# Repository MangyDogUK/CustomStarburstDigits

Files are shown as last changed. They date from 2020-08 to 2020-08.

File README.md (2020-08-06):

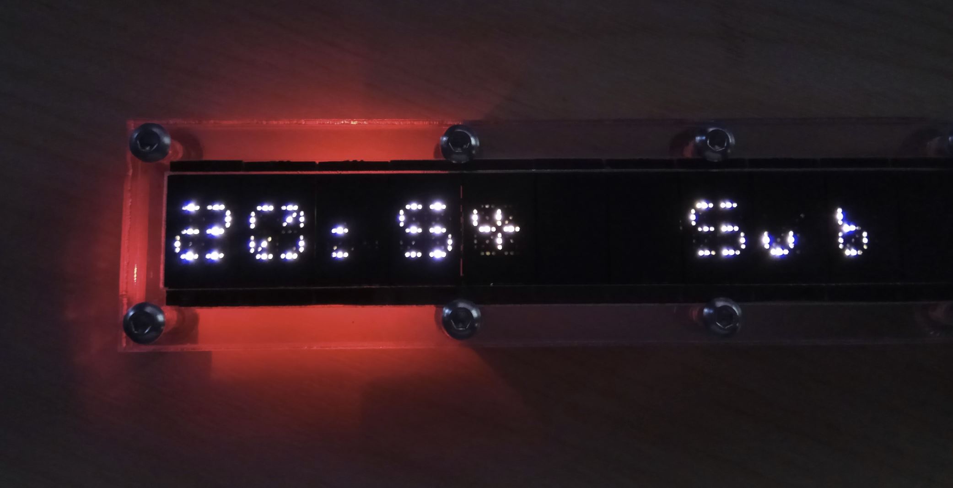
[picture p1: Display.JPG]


Custom Modular Starburst Digit
 
A Custom designed modular Starburst Digit, inspired by the displays on the Hornet fighter jet. 
Taking the original concept of the displays from the 1970s, that used tungsten bulbs, and used fibreoptic light pipes to light the segments of the display.
This project takes the visual concept and modernises it, using LEDs and shift registers to create a modular daisy-chainable display system.

At the time of writing this, the included software is functional and has only a few minor bugs and not all planned features are written. 

The digits use an arduino (atmega328p) to drive them, and basic functions are working as they should. Currently not written, is scrolling text and targeted led control through serial.

The digits receive data through SPI hardware and a hardware timer constantly drives the display, printing out a saved buffer. The software updates that buffer and in turn the display starts displaying that data.

Currently I'm realsing this under the Creative Commons License. 
Basic gist, feel free to use this and modify any designs for personal use. That could be making your own displays or even to use in your own built flightsims.
What you cant do is commercialise this project or derivative of this project in any way.

If you wish to commercialise this, to sell or make units to sell contact me and we can arrange a license fee, as well as more in-depth support.

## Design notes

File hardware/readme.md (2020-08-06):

Kicad project file, including schematic and pcb design.

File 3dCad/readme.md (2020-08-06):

3D cad files and images for the face of the digit.

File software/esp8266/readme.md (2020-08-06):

Data gathering and writing to display controller....
I used guides for time and youtube apis, but digit writing code is fully custom.
I will likely convert this class into a easily transportable library at some point.
the digits control class should work with any MCU.

One current known bug which I've yet to figure out... In some combinations of text being sent (in my case time and sub count) I get a bad checksum. Whats actually happening is a 0x02 frame start byte is being sent just before the 0x03 frame end byte in the packet. This throws off the checksum on the control MCU side as it expects the last two bytes before the frame end byte to be the checksum value. 

This doesnt happen all the time, and its certainly not programmed to do this. I will try to fix this when I have more free time to do so.

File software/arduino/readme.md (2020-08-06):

The digits are driven by an atmega328p, I used a arduino pro mini.
The shift registers are connected to SPI hardware that constantly driven by the hardware timer. 
The data is sent in an interlaced 4 row cycle... and currently the sweet spot seems to be data being sent at a 500ns interval, which is more than fast enough for vision persistance without any flicker or phase issues with PWM dimming.

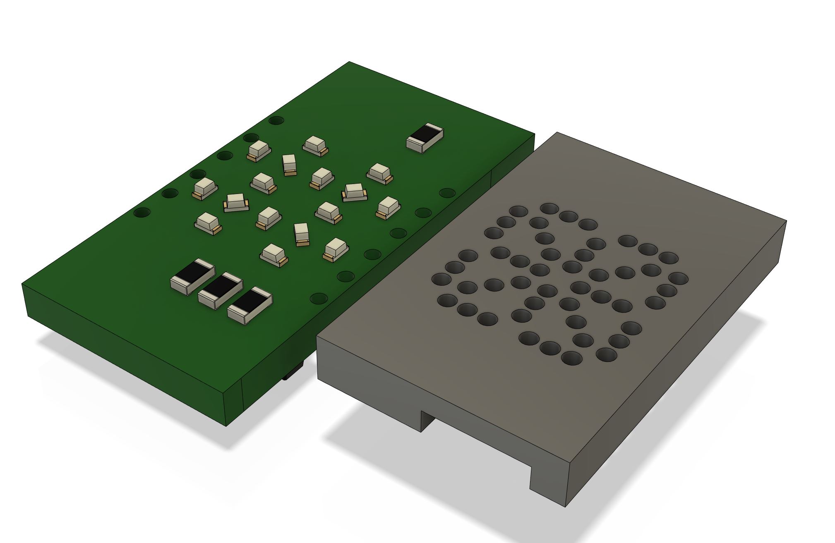
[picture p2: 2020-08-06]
3dCad/engraveref2.JPG

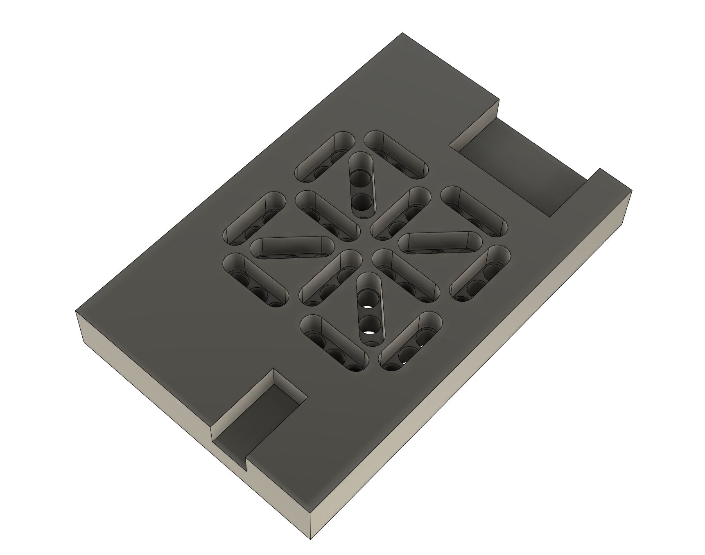
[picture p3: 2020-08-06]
3dCad/engraveref1.JPG

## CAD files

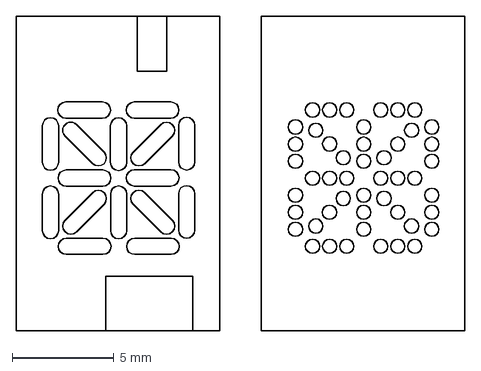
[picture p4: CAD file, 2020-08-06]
3dCad/CutAndEngraveReference.dxf
22.1 x 15.5 mm

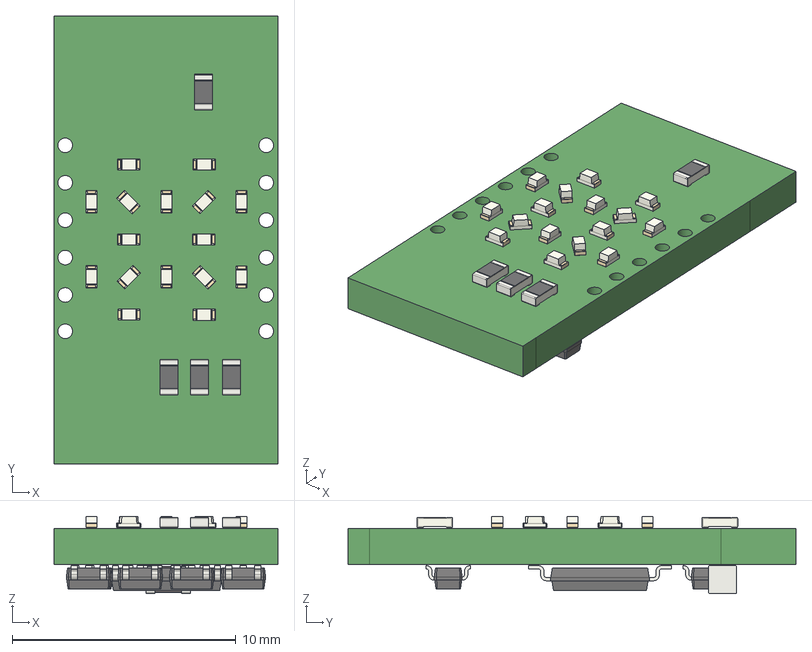
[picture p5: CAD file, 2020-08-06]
3dCad/StarBurstDigits.step
10.0 x 20.0 x 3.45 mm

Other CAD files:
3dCad/DigitDisplay.f3z

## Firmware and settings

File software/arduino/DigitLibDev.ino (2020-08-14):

#include "Arduino.h"
#include <SPI.h>
#include "characters.h"  //view and edit to add your own custom characters

#define lat 10 //latch though will be redister port controlled
#define PWMpin 6 // pin running brightness pwm
#define defaultBrightness 20
uint8_t brightness = defaultBrightness;

#define digitCnt 15 //count of digits to stream

boolean scroll = false;
boolean animate = false;
uint8_t animateOp = 1;
uint8_t charBuffer[digitCnt]; // input buffer for character to display, data taken from serial in from ESP8266

uint8_t scrollcharBuffer[60]; //holding space for scrolling text

//A function takes the characters and converts them to the interlaced streams bellow.
uint8_t interlaceA[digitCnt]; //data for row A
uint8_t interlaceB[digitCnt]; //data for row B
uint8_t interlaceC[digitCnt]; //data for row C
uint8_t interlaceD[digitCnt]; //data for row D

void encodeStream()
	{
		for (int i = 0; i < digitCnt; i++)
			{
				uint16_t character = returnMatch(charBuffer[i]);
				/*e.g the char 'A' returns 0b1110011010010011 which is 4 chunks of 4bits 1110, 0110, 1001, 0011.

				 I need to separate these four chunks and split them across interlace ABC and D, and add 1000 0100 0010 and 0001
				 to the end of each chunk as theyre deposited in the interlace arrays. */

				interlaceA[i] = (((character >> 8) & 0xF0) | (1 << 3)); //taking top 4 bits and setting bit 4 to 1 should give 11101000 for row a of character A
				interlaceB[i] = (((character >> 4) & 0xF0) | (1 << 2)); //taking top 4 bits and setting bit 4 to 1 should give 01100100 for row b of character A
				interlaceC[i] = (((character >> 0) & 0xF0) | (1 << 1)); //taking top 4 bits and setting bit 4 to 1 should give 10010010 for row c of character A
				interlaceD[i] = (((character << 4) & 0xF0) | (1 << 0)); //taking top 4 bits and setting bit 4 to 1 should give 00110001 for row d of  character A

			}

	}
/*
 * 							#	D3	#					#	A1	#
 * 				#		#							#							#		#
 * 				D			D						D					A				A
 * 				4					1				2			4						2
 * 				#							#		#		#							#
 * 							#	C1	#					#	A3	#
 * 				#							#		#		#							#
 * 				C					C				B				B					B
 * 				4			3						4						1			2
 * 				#		#							#							#		#
 * 							#	C2	#					#	B3	#
 */
#define a1 0b0000000000000010;
#define a2 0b1000000000000000;
#define a3 0b0100000000000000;
#define a4 0b0000010000000000;
#define a5 0b0000001000000000;
#define a6 0b0000000001000000;
#define a7 0b0000000000010000;
#define a8 0b0000000000000001;

uint8_t frame = 0;
uint16_t toEncode = 0;
void encodingAnimation(uint8_t digit, uint16_t data)
	{
		for (uint8_t i = 0; i < digitCnt; i++)
			{
				if (i == digit)
					{
						interlaceA[i] = (((data >> 8) & 0xF0) | (1 << 3)); //taking top 4 bits and setting bit 4 to 1 should give 11101000 for row a of character A
						interlaceB[i] = (((data >> 4) & 0xF0) | (1 << 2)); //taking top 4 bits and setting bit 4 to 1 should give 01100100 for row b of character A
						interlaceC[i] = (((data >> 0) & 0xF0) | (1 << 1)); //taking top 4 bits and setting bit 4 to 1 should give 10010010 for row c of character A
						interlaceD[i] = (((data << 4) & 0xF0) | (1 << 0)); //taking top 4 bits and setting bit 4 to 1 should give 00110001 for row d of  character A
					}
				else
					{
						interlaceA[i] = 0;
						interlaceB[i] = 0;
						interlaceC[i] = 0;
						interlaceD[i] = 0;
					}
			}

	}

#define frameDelay 20
void encodeAnimation()
	{
		brightness = defaultBrightness + 50;
		analogWrite(PWMpin, brightness);
		for (uint8_t i = (digitCnt * 2 + 1); i > 0; i--)
			{
				if (i % 2 == 0)
					{
						toEncode = a2
						;
						encodingAnimation((i / 2) - 1, toEncode);
					}
				else
					{
						toEncode = a1
						encodingAnimation((i / 2) - 1, toEncode);
					}
				delay(frameDelay);
			}

		for (uint8_t i = 0; i < 2; i++)
			{
				if (i < 2)
					{
						if (i % 2 == 0)
							{
								toEncode = a3

								encodingAnimation(0, toEncode);
							}
						else
							{
								toEncode = a4

								encodingAnimation(0, toEncode);
							}
					}
				delay(frameDelay);
			}

		for (uint8_t i = 0; i < (digitCnt * 2); i++)
			{

				if (i % 2 == 0)
					{
						toEncode = a5
						encodingAnimation(i / 2, toEncode);
					}
				else
					{
						toEncode = a6
						encodingAnimation(i / 2, toEncode);

					}

				delay(frameDelay);
			}

		for (uint8_t i = 0; i < 2; i++)
			{
				if (i < 2)
					{
						if (i % 2 == 0)
							{
								toEncode = a7

								encodingAnimation(digitCnt - 1, toEncode);
							}
						else
							{
								toEncode = a8

								encodingAnimation(digitCnt - 1, toEncode);
							}
					}
				delay(frameDelay);
			}
		brightness = defaultBrightness;
		analogWrite(PWMpin, brightness);
	}

uint8_t row = 0; //control for what row to draw, flipping to the next row each time timer triggers this function.
void shiftDisplay()
	{

		uint8_t d = 0; //d for digit
		//digitalWrite(lat, LOW);
		PORTB &= ~(1 << 2);

		switch (row)
			{
		case 1:
			for (d = 0; d < digitCnt; d++)
				{
					SPI.transfer(interlaceA[d]);
				}
			break;

		case 2:
			for (d = 0; d < digitCnt; d++)
				{
					SPI.transfer(interlaceB[d]);
				}
			break;

		case 3:
			for (d = 0; d < digitCnt; d++)
				{
					SPI.transfer(interlaceC[d]);
				}
			break;

		case 4:
			for (d = 0; d < digitCnt; d++)
				{
					SPI.transfer(interlaceD[d]);
				}
			row = 0;
			break;
			}
		//digitalWrite(lat, HIGH);
		PORTB |= (1 << 2);
		row++;

	}

void setup()
	{
		Serial.begin(115200);
		SPI.begin();
		SPI.setBitOrder(LSBFIRST);

		pinMode(lat, OUTPUT);		//latch

		pinMode(PWMpin, OUTPUT);//PWM brightness control will add control command in serial
		analogWrite(PWMpin, brightness);		//default to 20 (8bit)

		for (int i = 0; i < digitCnt; i++) // just to make sure display is empty on startup... Probably not needed.
			{
				charBuffer[i] = ' ';
				interlaceA[i] = 0;
				interlaceB[i] = 0;
				interlaceC[i] = 0;
				interlaceD[i] = 0;
			}

//////////////////////////////////////////////////////////////////////////////////
//setting display timer interrupt to keep a smooth display refresh
//The timer runs the display constantly.
		noInterrupts();// disable all interrupts
		TCCR1A = 0;
		TCCR1B = 0;

		TCCR1B &= ~(1 << WGM12); // WGm02 bit set to zero? for normal mode, to not clear on compare match? Is this right?
		/*WGM02:0=0 according to 328 datasheet, another example calls for WGM12...confusing*/
		TCCR1B &= ~(1 << CS12);    // 8 prescaler 2 ticks per uS
		TCCR1B |= (1 << CS11);
		TCCR1B &= ~(1 << CS10);

		TIMSK1 |= (1 << OCIE1A);  //Output compare eneabled
		OCR1A = 100; //10=500ns trigger
		TCNT1 = 0; //reset to zero

		interrupts();             // enable all interrupts
//////////////////////////////////////////////////////////////////////////////////
		String hw = "--=  Hello  =--";
		for (int i = 0; i < digitCnt; i++)
			{
				charBuffer[digitCnt - i - 1] = hw[i];
			}
		encodeStream();
		delay(1000);

		encodeStream();
		delay(2000);

		Serial.flush();    //clean out the serial junk esp8266 dishes out on startup
		delay(1000);

	}

//timer interrupt that runs the display
ISR(TIMER1_COMPA_vect)
	{
		shiftDisplay();
		TCNT1 = 0; //reset to zero
	}

uint8_t serialBuffer[65];
uint8_t serialBuffCount = 0;

bool newFrame = false;
bool packetReady = false;
uint8_t lastData = 0;
//following ACSII codes to keep some standard to follow.....
#define startFrame 0x02 //acsii code STX
#define endFrame 0x03 //acsii code ETX
#define ESC 0x1B //acsii code
#define ACK 0x06 //acsii code
#define NAK 0x15//acsii code

void resendSerial()
	{
		//dispDebug("BAD    ");
		//command resend last packet  why these bytes? just random ones that ill match in the other mcu to use as a resend (B.A.D)
		Serial.write(NAK);
	}
void confirmSerial()
	{
		//dispDebug("FAB    ");
		// confirm received packet no issues... Maybe will add a auto resend if no confirmation on other mcu F.A.B (thunderbirds... , cant do S.I.G for Captain Scarlet D: )
		Serial.write(ACK);
	}
void flush()
	{
		uint8_t chard = 0;
		while (Serial.available() > 0)
			{
				chard = Serial.peek();
				if (chard != startFrame)
					{
						Serial.read();
					}
				else
					{
						break;
					}
			}
		newFrame = false;
		serialBuffCount = 0;
	}

void getSerial()
	{

		/*
		 Serial structure  uint8_t chars[21]{startFrame,0xA0,'A','B','C','D','E','F','G','H','I','J','K','L','M','N','O','\n',0,0,endFrame};
		 | Header Byte | Length of Packet including Header and 2 byte checksum, in integer (ir 10 bytes 20 40 50...)| Data | 2 byte Checksum |

		 Start Frame | Header Byte  |							 Data		 								|											 Checksum 												|  End Frame
		 Fixed digit display	=						0x02							0xA0								char Stream	+\n						sum of bytes added up bytes							0x03												Note:		Non scrolling fixed display, char stream should be limited to character count
		 Scrolling display   	=						0x02							0xB0								char Stream		+\n					sum of bytes added up bytes							0x03 											Note:		Scrolling display, char stream limited to 60 characters, can be increased by increasing serialBuffer global, but buffer must also include space for header length and checksum.
		 Special Animate			=						0x02							0xC0						Animation option	+\n			sum of bytes added up bytes							0x03												Note:		Triggers special scrited animation
		 Target Led								=						0x02							0xD0						2b Hex + Digit	+\n					sum of bytes added up bytes							0x03												Note: 		Targeted Led turn on, 2 byte data using Hex to address leds and dec to address digit e.g 0xA2 and 4 = Led A2 of Digit 4, 0xB4 + 23 = Led B4 of digit 23.

		 */

		uint8_t data = Serial.read();
//get serial data
		if (data == startFrame && lastData != ESC)
			{
				newFrame = true;
				packetReady = false;
				serialBuffCount = 0;
				serialBuffer[0] = data;
				lastData = data;

				//	dispDebug(" frame start ");

			}

		if (data == endFrame && lastData != ESC)
			{
				newFrame = false;
				packetReady = true;
				serialBuffer[serialBuffCount++] = data;
				lastData = data;

				//	dispDebug(" end frame ");
				// code to end the frame
			}

		//checking all states though maybe superfluous as the grabs for framing and esc is above...
		if (((data == endFrame && lastData == ESC)
		    || (data == startFrame && lastData == ESC)
		    || (data == ESC && lastData == ESC)
		    || (data != endFrame || data != startFrame || data != ESC))
		    && packetReady == false)
			{
				serialBuffer[serialBuffCount++] = data;
				lastData = data;
			}

		if (packetReady == true)
			{
				uint8_t command = serialBuffer[1];

				uint8_t length = 0;
				while (true) // work out length of message
					{
						if (serialBuffer[length] != '\n')
							{
								length++;
							}
						else
							{
								break;
							}
					}

				length = length - 2; //Length of message minus startFrame and Command byte
				uint8_t text[length] = { 0 };

				// error check//

				//head check
				if (serialBuffer[1] != 0xA0 && serialBuffer[1] != 0xB0
				    && serialBuffer[1] != 0xC0 && serialBuffer[1] != 0xD0) //expected headers, add any headers you like for extra commands
					{ //invalid head

						uint8_t head = serialBuffer[1];
						char buffer[15];
						sprintf(buffer, " Bad Head %x  ", head);
						dispDebug(buffer);

						flush();
						resendSerial();
						goto failEnd;
					}

				//checksum check
				//add up checksum this side
				uint16_t checksum = 0; // to calculate

				for (int c = 0; c < length + 3; c++) //Length + \n + start frame + command byte = +3
					{
						if (serialBuffer[c] != ESC) //ignore escape bytes in checksum, as ignored in the generation
							{
								checksum = checksum + serialBuffer[c];
							}

					}

				//Reconstitute received checksum two bytes for 16bit int.
				//Bug fix, before ESC wasnt handled in checksum bytes, now its captured and bytes offset.
				//not the tidest of code but its working so far.
				char buffer[15];

				uint8_t readStart = length + 3;

				uint8_t escOffset1 = 0;
				if (serialBuffer[readStart] == ESC)
					{
//					sprintf(buffer, " off1 %i  ", serialBuffer[readStart]);
//					dispDebug(buffer);
//					delay(500);

						escOffset1 = 1;
					}

				uint8_t escOffset2 = 0;
				if (serialBuffer[readStart + 1 + escOffset1] == ESC)
					{
//						sprintf(buffer, " off2 %i  ", serialBuffer[readStart+1+escOffset1]);
//						dispDebug(buffer);
//						delay(500);

						escOffset2 = 1;
					}

				uint8_t checkHIGH = serialBuffer[(readStart + escOffset1)];
				uint8_t checkLOW =
				    serialBuffer[(readStart + 1 + escOffset1 + escOffset2)];

//						sprintf(buffer, " cs1 %i  ", checkHIGH);
//						dispDebug(buffer);
//						delay(500);
//
//						sprintf(buffer, " cs2 %i  ",  checkLOW);
//						dispDebug(buffer);
//						delay(500);

				uint16_t checksumRe = checkHIGH << 8 | checkLOW << 0;
				//Compare received against this side added up checksum

				if (checksum != checksumRe)
					{
						uint16_t cs = checksumRe;

						sprintf(buffer, " cs %i  ", cs);
						dispDebug(buffer);
						delay(1000);

						//checksum failed resend packet
						flush();
						resendSerial();
						goto failEnd;
					}

//run data

				bool ignore = false;
				uint8_t targetByte = 0;

				for (uint8_t i = 0; i < length; i++)
					{ // +3 as thats the text portion of the packet
						if (serialBuffer[i + 3] == ESC
						    && (serialBuffer[i + 4] == startFrame
						        || serialBuffer[i + 4] == endFrame
						        || serialBuffer[i + 4] == ESC))
							{
								ignore = true;
							}
						else
							{
								ignore = false;
							}

						if (ignore == false)
							{
								text[targetByte] = serialBuffer[i + 2];
								targetByte++;
							}
					}

				if (serialBuffer[1] == 0xA0) 	//display fixed readout of text
					{
						scroll = false;
						animate = false;
						for (uint8_t i = 0; i < length; i++)
							{
								charBuffer[i] = text[length - 1 - i]; //transfering data to the display buffer for encoding.
							}
						encodeStream();
					}

				if (serialBuffer[1] == 0xB0) //scrolling text, code not written yet for this.... by all means finish it.
					{
						scroll = true;
						animate = false;
						for (uint8_t i = 0; i < length; i++)
							{
								charBuffer[i] = text[length - i]; //transfering data to the display buffer for encoding.
							}
						//set scrolling triggers and encode loops.......
					}

				if (serialBuffer[1] == 0xC0) 	//set animations, only one at the moment
					{
						scroll = false;
						animate = true;
						if (text[0] == "1")
							{
								animateOp = 1;
							}
					}

				if (serialBuffer[1] == 0xD0) //target led, code not written for this yet. But serial is fast enough that in theory you could run animations from host mcu
					{
// Write something interesting here that people might read!
					}

				failEnd: // if checks fail skips to here
				for (int i = 0; i < sizeof(serialBuffer); i++)
					{
						serialBuffer[i] = NULL;
					}
				packetReady = false;
			}
	}

void dispDebug(String msg)
	{
		for (int i = 0; i < digitCnt; i++)
			{
				charBuffer[digitCnt - i - 1] = msg[i];
			}
		encodeStream();
		delay(50);
	}
int cnt = 0;
void loop()
	{
		if (Serial.available() > 0)
			{
				getSerial();
			}
		else
			{
				if (animate == true)
					{
						encodeAnimation();
					}
			}

	}

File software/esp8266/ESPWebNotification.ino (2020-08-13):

/***************************************************************************
 This program uses a mix mash of various guides found online for using common online API's
 for getting data such as the time and sub stats.

 Swap the credentials out for your own........

 Data handling and encoding is custom designed for the display. And any edits you make to the
 code here must be reflected in the display hardware control  program on the arduino.

 I will try to keep this human readable and relatively easy to follow......... I say I'll try cant guarantee it...!

 ****************************************************************************/
#include "Arduino.h"
//The setup function is called once at startup of the sketch
#include <ESP8266WiFi.h>
#include <time.h>


const char* ssid = "Dog-Fluff-Everywhere!"; // place your SSID here
const char* password = "love-sex-secret-god-password-hack_the_planet"; //Place your password here!

#include <WiFiClientSecure.h>
//https://github.com/witnessmenow/arduino-youtube-api
#include <YoutubeApi.h>
#include <ArduinoJson.h>
//////////////////////////////////////////////////////////////////////////////////////////
#define API_KEY "KeysKEYS-EVERYWHERE"  // your google apps API Token
#define CHANNEL_ID "YOUR ID NOT MINE" // makes up the url of channel
//////////////////////////////////////////////////////////////////////////////////////////

WiFiClientSecure client;
YoutubeApi api(API_KEY, client);

long subs = 0;


#define bufferSize 65


class displayDigits
	{
//special serial bytes following ACSII codes to keep some standard to follow.....
#define startFrame 0x02 //ascii code STX
#define endFrame 0x03 //ascii code ETX
#define ESC 0x1B //ascii code
#define ACK 0x06 //ascii code
#define NAK 0x15//ascii code

private:
	char buffer[bufferSize]; //65 being arbitrary 60 characters plus  special bytes ... Raise it if you like, but be sure to raise it in the arduino sketch as well
	bool scrolling = false;
	uint8_t digitCnt;

	void checksum() // calculates checsum and injects it into the packet
		{
			uint16_t checkSum = 0;
			int c = 0;
			while (true)
				{
					if (buffer[c] != '\n')
						{
							checkSum = checkSum + buffer[c];
							c++;
						}
					else
						{
							checkSum = checkSum + buffer[c];
							break;
						}
				}
			buffer[c + 1] = checkSum >> 8;
			buffer[c + 2] |= checkSum << 0 & 0xff;
		}

public:

	displayDigits(uint8_t digits)
		{
			digitCnt = digits;
		}

	void setText(bool scroll, char *text)
		{
			scrolling = scroll;

			buffer[0] = startFrame;

			int c = 0;
			if (scrolling == false)
				{
					buffer[1] = 0xA0;
				}
			else
				{
					buffer[1] = 0xB0;
				}
			while (true)
				{
					if (text[c] != '\n') // part of the bug now corrected
						{
							buffer[2 + c] = text[c];
							c++;
						}
					else
						{
							buffer[2 + c] = text[c];
							break;
						}
				}

		//checksum(); // calculates checsum and injects it into the packet

			buffer[c + 3] = endFrame;

		}
	void setAnimation(char ani)
		{
			buffer[0]=startFrame;
			buffer[1] = 0xC0;
			buffer[2]=ani;
			buffer[3]='\n';
			buffer[6] = endFrame;
		}

	void write(void)
		{
			uint16_t checkSum = 0;

			int c = 0;
			while (true)
				{
					if (buffer[c] != '\n')
						{
							checkSum = checkSum + buffer[c];
							c++;
						}
					else
						{
						checkSum = checkSum + buffer[c];
							break;
						}
				}
			buffer[c + 1] = checkSum >> 8;
			buffer[c + 2] = checkSum << 0;

			uint8_t offset = 0;

			for (int i = 2; i <(c + 3 + offset); i++) //inject ESC in message and checksum if special bytes were used
				{
					if ((buffer[i] == startFrame && buffer[i - 1] != ESC)
					    || (buffer[i] == endFrame && buffer[i - 1] != ESC))
							//|| (buffer[i] == ESC && buffer[i - 1] != ESC))

						{
							for (int s = (c + 3+offset); s >=i; s--)
								{
									buffer[s+1] = buffer[s];
								}
								offset++;
						buffer[i] = ESC;
						}

				}

			buffer[c + 3 + offset] = endFrame;  // fixed, turns out I didnt have an end frame byte set D: Not sure how my code worked at all!

			for (int i = 0; i <(c + 4 + offset); i++)
				{
					Serial.write(buffer[i]);
				}
		}
	};



int timezone = 0;
int dst = 0;

displayDigits myDigits = displayDigits(15); //setting the number of digits in chain

void setup()
	{

		Serial.begin(115200);

		Serial.setDebugOutput(0);//a way to force off the debug output, causing issues. Still not working though.....

		delay(100);
		WiFi.mode(WIFI_STA);
		WiFi.begin(ssid, password);


		delay(1000);
		myDigits.setAnimation('1');
		myDigits.write();
		delay(1000);

		while (WiFi.status() != WL_CONNECTED)
			{

				delay(1000);
			}
		 client.setInsecure();


		configTime(1 * 3600, 0, "pool.ntp.org", "time.nist.gov");

		while (!time(nullptr))
			{

				delay(1000);
			}

	}
unsigned long timeBetweenRequests = 2400000;
unsigned long nextRunTime;
uint16_t subCount=0;

void loop()
	{
		 if (millis() > nextRunTime)  {
		    if(api.getChannelStatistics(CHANNEL_ID))
		    {
		    		subCount=api.channelStats.subscriberCount;
		    }
		    nextRunTime = millis() + timeBetweenRequests;
		  }


		time_t rawtime;
		struct tm *timeinfo;

		time(&rawtime);
		timeinfo = localtime(&rawtime);

		char timeChar[6];
		strftime(timeChar, sizeof(timeChar), "%H:%M", timeinfo);

		char buffer[bufferSize];
		sprintf(buffer,"%s  Sub %i\n",timeChar,subCount);//end in \n new line otherwise program will get stuck in a constant loop

		myDigits.setText(false, buffer);
		myDigits.write();

		delay(1000);
	}

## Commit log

2020-08-06 Kicad project file, schematic and pcb, hopefully with cached library
2020-08-06 PCB step file for reference
    [StarBurstDigits.step]
2020-08-06 f360 file for the digits face
    [DigitDisplay.f3z]
2020-08-06 DXF for cutting and engraving the face.
    [CutAndEngraveReference.dxf]
2020-08-06 corrected minor mistake in pcb
2020-08-13 Fixed typos
    line 107 might be wrong, appears it the while should be text not buffer, but text doesnt work... will investigate further.
    [ESPWebNotification.ino]
2020-08-13 Potentially fixed packet bug
    Its a wonder how this worked at all tbh, friend found mistake in my text set code. I mixed up 2 variables...
    That highlighted another mistake. Some how I completely forgot to write the endFrame byte in my code. How on earth this byte ended up being in the buffer at all.... really strange.
    Corrected now. Maybe fixed.
    But discovered esc handling isnt working on display controller side. Need to fix that.
    [ESPWebNotification.ino]
2020-08-14 Bug fix, checksum didnt have ESC handling
    Corrected a mistake on the getSerial function, when building the checksum value from the packet, there was no ESC handling for special bytes that would inevitable show up in checksum value.
    Made some rather messy offset ESC handling, seems to be working for now.
    [DigitLibDev.ino]
